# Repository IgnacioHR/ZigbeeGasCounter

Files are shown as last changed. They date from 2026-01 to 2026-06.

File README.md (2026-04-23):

# Zigbee GAS counter

This project is a DIY Zigbee-enabled gas meter that measures and tracks gas consumption. The device integrates with Zigbee2MQTT and Home Assistant, providing accurate readings for energy management and analysis. It’s designed to be battery-powered and operate autonomously, addressing common challenges of similar solutions.

## Features

- Real-time gas consumption tracking in cubic meters (m³).
- Real-time gas flow tracking in cubit meters per hour (m³/h)
- Zigbee communication for seamless integration with Zigbee2MQTT and Home Assistant.
- Battery-powered for installation flexibility.
- Double battery connector to allow battery replacement without counting interruption.
- Built-in counter to prevent data loss if the network or Home Assistant goes offline.
- Easy setup and minimal hardware requirements.
- OTA firmware updatable.
- Device button with rich functionality 

## Screenshots

Below are some screenshots of the device integrated into Zigbee2MQTT:

Main device
Exposes
Bind
Reporting
Clusters

## Why Zigbee for DIY Projects?

Zigbee is a low-power, reliable wireless protocol ideal for IoT devices. Unlike Wi-Fi, Zigbee consumes minimal energy, making it perfect for battery-operated devices. While commercial Zigbee gas meters aren’t readily available, this project demonstrates how to build one from scratch using affordable components and the ESP32-C6 module.

## How It Works

1. The gas meter’s rotating wheel has a built-in magnet.
1. A magnetic sensor detects each full rotation of the wheel, corresponding to a predefined volume of gas.
1. The ESP32-C6 processes the data, maintaining a cumulative counter (currentSummDelivered) and calculating instantaneous demand (instantaneousDemand) in m³/h.
1. These metrics are sent via Zigbee to Zigbee2MQTT, which forwards them to Home Assistant.

## Motivation

Before this project, I used a modified door sensor to monitor gas usage. While functional, it had several drawbacks:

1. **Short battery life**: The door sensor required frequent battery replacements.
2. **Data loss**: If Zigbee2MQTT or Home Assistant went offline, pulse data was lost, leading to discrepancies.
3. **Complexity**: Managing counters and automations in Home Assistant was cumbersome.

After searching for commercial Zigbee gas meters and finding none, I decided to create a custom device tailored to my needs.

Old device

## Device button functionality

The device button has implemented gesture recognition. The gestures signaled are PRESS, RELEASE, SINGLE_CLICK, DOUBLE_CLICK and HOLD. In the code there are more gestures such as NONE (No current gesture set) and UNKNOWN_CLICK (set when failing to recognize any of the properly defined gestures).

Once a gesture is recognized, the functionality attached, if any, is raised:

- PRESS: The button is pressed. The internal led is switched on. Zigbee radio is enabled.
- SINGLE_CLICK: The button is pressed and released in less than 400ms and not pressed again in 400ms. Force report of the Current Summation Delivered, Battery percentage, Status and extended Status registers. The Battery voltage is updated internally at this time. Note it is not reported because it is not possible in the Zigbee specifications.
- DOUBLE_CLICK: The button is pressed and releasses in less than 400ms, then pressed again in less than 400ms and released in less than 400ms and not pressed in less than 400ms. The device is restarted (counter is not reset)
- HOLD: The button is keep pressed for 3 seconds. The device leaves the network and starts comission process to find another network.
- NONE: The led is turned off, note the led is turned off for multiple other causes such as entering sleep mode etc.

## Project Status

April 23rd 2026 - First results of battery total duration in Light-Sleep and Deep-Sleep configurations. See below. OTA issues are now fixed
March 2nd 2026 - Now testing in LIGHT_SLEEP mode.This project is in testing phase. It is now deployed for real gas consumption measurement at home.

Remaining issues are:

* (Voltage should be transmitted now, but this is not fully tested) Voltage value is not transmitted to the server as part of the value report (in zigbee terms) I actually I know i can force read the value from the server but I don't know how to push the value from the device to the server.

* (This is now a lesson learned, not an issue) The initial decission about using a 2S LiPo battery causes more troubles than benefits. I finally decided to go 1S LiPo battery and use the internal Seed-Studio 3v switching regulator and charger module.

* (April 2026 this is now fixed) OTA is no longer functional at all. I know about changes around OTA functionality in zigbee2mqtt and more testing is required.

### What is missing and how you can help

See the **Project Status** section above for specific issues. If you can help I'll be more than happy.

For discussions and contributions, please join the ongoing thread on the Home Assistant Community: 👉 [Zigbee Gas Counter](https://community.home-assistant.io/t/zigbee-gas-counter/833557)

One of my main concerns is **power consumption and battery life**. The software includes battery status measuring and reporting.
#### First comparison analysis of the battery duration under Light-Sleep and Deep-Sleep configurations
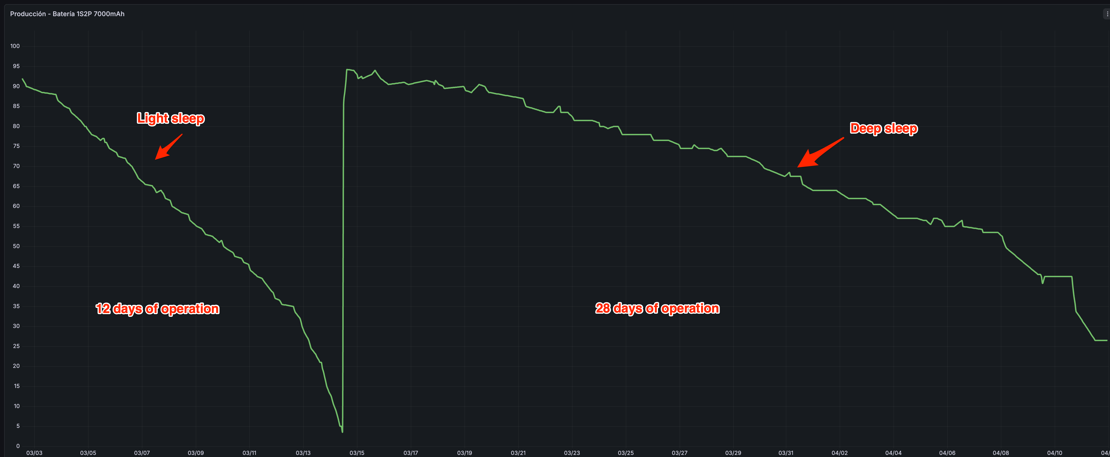
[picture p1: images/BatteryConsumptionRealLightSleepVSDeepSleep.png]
Main device


I've recently seen [this video](https://youtu.be/KE7bOYCYETM?si=DaY46TMaGhLbYbze) from @"Microamp Home" on YT and it looks worth testing using one of the devices from Nordic Semiconductors.

Currently, the testing prototype runs on a Seed Studio ESP32-C6, but the long-term goal is to use only the **ESP32-C6 chip**, eliminating unnecessary components. To achieve this, I will need help reviewing schematics and PCB designs, as **I’m not an expert in hardware design—just an enthusiast**. If you have experience in this area, your input would be greatly appreciated.

## Getting Started

### Required Hardware

To build this project, you’ll need:

- **Seed Studio ESP32-C6** or a compatible development board.
- **Magnetic reed switch** for pulse detection.
- **10kΩ resistors** (pull-down).
- **3.6 LiPo battery**. TBD
- Optional: Custom 3D-printed enclosure for the hardware.
- Optional: External 2.4 Ghz antena.

### Software Requirements

- **ESP-IDF (Espressif IoT Development Framework)**: [Installation Guide](https://docs.espressif.com/projects/esp-idf/en/latest/esp32/get-started/index.html)
- **Zigbee2MQTT**: [Setup Guide](https://www.zigbee2mqtt.io/)
- **Home Assistant**: [Official Website](https://www.home-assistant.io/)

## **Setup Instructions**

### **1. Clone the Repository**

First, download the project code from the GitHub repository:

```bash
git clone https://github.com/IgnacioHR/ZigbeeGasCounter.git
cd ZigbeeGasCounter
```

### **2. Configure the target chip**

Set the corrent target for the ESP32-C6:

```bash
idf.py --preview set-target ESP32C6
```

### **3. Install Dependencies**

Ensure ESP-IDF and its tools are installed on your machine.

### **4. Erase Flash Memory**

Clear previous configurations:

```bash
idf.py -p PORT erase-flash
```

### **4. Build and Flash**

Compile the code and flash it to the ESP32-C6 board:

```bash
idf.py build
idf.py -p PORT flash
idf.py -p PORT monitor
```

### **5. Hardware configuration in the source code

Edit the file *esp_zb_gas_meter.h* and head to the section **FEATURES CONFIGURATION** and the section **HARDWARE CONFIGURATION** you can change the chip pins to be used or leave them as they are. You can also decide what features shall be enabled depending, for example, in the power source for your specific unig.

## Device operation and main button actions

The device has just one button, but multiple gestures are recognized

- Button press: When the main button is pressed, if the device was is sleep mode, zigbee radio is enabled. Note, button press is the first gesture of a possible list of gestures recognized
- Button release: No specific action is associated to this gesture. The time passed between the button press and release is used to determine more gestures as defined below.
- Single click: A single click is detected when the time between press and release is shorter than 250ms. When single click gesture is detected, the device shall refresh data on the server side, including the battery status and voltage value (note the voltage value is not refresh in the server side automatically, there is a note on this topic), device error conditions are reset and reevaluated again.
- Double click: A double click is detected when the time between press and release is sorter then 250ms and the button cycle is executed twice. When this gesture is recognized the device is reset.
- Unknown click: This happens when the user triple-click or press-click-press in a way that does not fit in a single or double click. No action is associated to this gesture.
- Long press: When the button is pressed and not released for 3 seconds, the device is ordered to leave the network and start the commision process to join an open network again.

### NVS (Non-Volatile Storage)

The cumulative gas consumption (currentSummDelivered) is stored in the device’s NVS to prevent data loss. The counter is automatically restored upon reboot.

### Battery Optimization

The device uses sleep modes to conserve energy. It wakes up:

- When gas consumption is detected.
- Periodically (e.g., every hour) to send reports.

## Customization

You can adapt this project for other pulse-based meters (e.g., water or electricity) by modifying the code to reflect the appropriate measurement units and formulas.

## Manufacturer information

This project includes a custom manufacturer name and code:

- Name: “MICASA” – A playful mix of “mi casa” (my home) in Spanish.
- Code: 0x8888 – Chosen arbitrarily for this DIY project.

## SDK Resources

- [ESP Zigbee SDK Docs](https://docs.espressif.com/projects/esp-zigbee-sdk)
- [ESP Zigbee SDK Repo](https://github.com/espressif/esp-zigbee-sdk)

## Contributing

If you want to contribute or improve this project, feel free to fork the repository and open a pull request. Suggestions are welcome!

## TODO

Here are the planned improvements:

1. Design a custom PCB for the ESP32-C6, connectors and resistors.
2. Create a 3D-printed enclosure for secure installation.
3. Light-Sleep mode, the chip is not entering Light-Sleep

## Acknowledgments

By improving the content structure and emphasizing actionable steps, this README not only serves as a guide for your project but also inspires others to create their own Zigbee devices.

## License

[License](https://creativecommons.org/licenses/by-nc-sa/4.0/deed.en)

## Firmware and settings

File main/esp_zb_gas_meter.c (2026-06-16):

/*
 * Zigbee Gas Meter - An open-source Zigbee gas meter project.
 * Copyright (c) 2025 Ignacio Hernández-Ros.
 *
 * This work is licensed under the Creative Commons Attribution-NonCommercial-ShareAlike 4.0
 * International License. To view a copy of this license, visit
 * https://creativecommons.org/licenses/by-nc-sa/4.0/
 *
 * You may use, modify, and share this work for personal and non-commercial purposes, as long
 * as you credit the original author(s) and share any derivatives under the same license.
 */
#include <string.h>
#include "esp_check.h"
#include "driver/gpio.h"
#include "nvs_flash.h"
#include "freertos/FreeRTOS.h"
#include "freertos/task.h"
#include "esp_sleep.h"
#include "sys/time.h"
#include "esp_timer.h"

#include "esp_zb_gas_meter.h"
#include "esp_zb_gas_meter_adc.h"
#include "esp_zb_gas_meter_zigbee.h"
#include "esp_zb_gas_ota.h"
#include "esp_zb_gas_led.h"

/* Experimental, check if we sleepy device can help the design */
#ifdef CONFIG_PM_ENABLE
#include "esp_pm.h"
#include "esp_private/esp_clk.h"
#endif

// amount of time to ignore a digital input pin interrupt repetition
#define REED_DEBOUNCE_TIMEOUT 1000U /* milliseconds */
#define BTN_DEBOUNCE_TIMEOUT 30 /* milliseconds */

/* Human interaction and device configuration */

// How long the MAIN BUTTON must be pressed to consider a LONG PRESS
#define LONG_PRESS_TIMEOUT 5 // seconds

#define NVS_NAMESPACE "gas_monitor"
#define NVS_KEY "counter"

#ifdef FEATURE_MEASURE_FLOW_RATE
#define TIME_TO_RESET_INSTANTANEOUS_D UINT32_C(12000)
#endif

const char *TAG = "GAS_COUNTER";

// Last time a pulse was received

// last time an interrupt occurred
RTC_DATA_ATTR struct timeval last_interrupt_time;

// RTC_DATA_ATTR int last_reel_state;
RTC_DATA_ATTR struct timeval last_reel_state_chage_time;

#ifdef FEATURE_MEASURE_FLOW_RATE
RTC_DATA_ATTR struct timeval last_increment_time;
#endif

// gracie period to avoid entering deep sleep when the zigbee radio has been turned on
#ifdef FEATURE_DEEP_SLEEP
struct timeval deep_sleep_gracie_period = {
    .tv_sec = 0,
    .tv_usec = 0
};
#endif

// When the main button is pressed a one time task is started
// to detect a long press without having to wait until
// the user releases the button
#ifdef FEATURE_DEEP_SLEEP
bool started_from_deep_sleep = false;
#endif

// true while leaving the network to prevent sending data to coordinator
bool leaving_network = false;

#ifdef FEATURE_DEEP_SLEEP
// sleep
RTC_DATA_ATTR struct timeval sleep_enter_time;
#endif

// Non volatile memory handle
nvs_handle_t my_nvs_handle;

#ifdef FEATURE_MEASURE_BATTERY_LEVEL
TaskHandle_t adc_task_handle = NULL;
#endif
TaskHandle_t zigbee_task_handle = NULL;
#ifdef FEATURE_DEEP_SLEEP
TaskHandle_t deep_sleep_task_handle = NULL;
#endif
TaskHandle_t save_counter_task_handle = NULL;
TaskHandle_t btn_press_task_handle = NULL;
TaskHandle_t btn_release_task_handle = NULL;
#ifdef FEATURE_DEEP_SLEEP
QueueHandle_t deep_sleep_queue_handle = NULL;
#endif
#ifdef FEATURE_MEASURE_FLOW_RATE
TimerHandle_t reset_instantaneous_demand_timer = NULL;
#endif
TimerHandle_t deep_sleep_timer = NULL;
#ifdef FEATURE_LIGHT_SLEEP
TimerHandle_t periodic_checks_timer = NULL;  // Timer for periodic radio/battery checks (event-driven instead of polling)
#endif
EventGroupHandle_t report_event_group_handle = NULL;
EventGroupHandle_t main_event_group_handle = NULL;

// Intelligent button gesture detection timers
TimerHandle_t timer_since_press_handler = NULL;
TimerHandle_t t_detect_hold = NULL;
TimerHandle_t timer_since_release_handler = NULL;

TaskHandle_t btn_task_handle = NULL;

// this is set to true when the device goes to sleep and the pulse pin is
// still high. The device will be turned on inmediately and we will
// avoid counting one tick until we detect it is down again
RTC_DATA_ATTR bool exception_pulse_button_on_hold = false;

#define CLICK_PRESS_TIME_MS       400    // MUST BE BIGGER THAN 150
#define CLICK_HOLD_TIME_MS       3000
#define CLICK_RELEASE_TIME_MS     400

typedef enum ButtonState_e {
    NONE = 0,
    PRESS,
    RELEASE,
    SINGLE_CLICK,
    DOUBLE_CLICK,
    UNKNOWN_CLICK,
    HOLD
} button_state_t;

button_state_t button_state = NONE;

// static portMUX_TYPE counter_spinlock = portMUX_INITIALIZER_UNLOCKED;

// Load counter value from NVS
esp_err_t gm_counter_load_nvs()
{
    esp_err_t err = nvs_open(NVS_NAMESPACE, NVS_READWRITE, &my_nvs_handle);
    if (err == ESP_OK)
    {
        uint64_t saved_count = 0;
        err = nvs_get_u64(my_nvs_handle, NVS_KEY, &saved_count);
        if (err == ESP_OK)
        {
            current_summation_delivered.low = saved_count & 0x00000000FFFFFFFF;
            current_summation_delivered.high = (saved_count & 0x0000FFFF00000000) >> 32;
            ESP_LOGI(TAG, "Counter loaded: low=%lu high=%u", current_summation_delivered.low, current_summation_delivered.high);
        }
        else
        {
            ESP_LOGI(TAG, "Counter not found in memory so starting from 0");
            err = ESP_OK;
        }
    }
    else
    {
        device_extended_status |= ESP_ZB_ZCL_METERING_NV_MEMORY_ERROR;
        device_status |= ESP_ZB_ZCL_METERING_GAS_CHECK_METER;
        xEventGroupSetBits(report_event_group_handle, STATUS_REPORT | EXTENDED_STATUS_REPORT);

        ESP_LOGE(TAG, "Error opening NVS: %s", esp_err_to_name(err));
    }
    return err;
}

// Task to save the counter to NVS when value changes
void save_counter_task(void *arg)
{
    while (true)
    {
        ulTaskNotifyTake(pdTRUE, portMAX_DELAY);
        uint64_t to_save_count = current_summation_delivered.high;
        to_save_count <<= 32;
        to_save_count |= current_summation_delivered.low;
        esp_err_t err = nvs_set_u64(my_nvs_handle, NVS_KEY, to_save_count);
        if (err == ESP_OK)
        {
            nvs_commit(my_nvs_handle);
            ESP_LOGI(TAG, "Counter stored: low=%lu high=%d", current_summation_delivered.low, current_summation_delivered.high);
            #ifdef FEATURE_DEEP_SLEEP
            if (deep_sleep_task_handle != NULL)
            {
                TickType_t deep_sleep_time = dm_deep_sleep_time_ticks();
                if (xQueueSendToFront(deep_sleep_queue_handle, &deep_sleep_time, pdMS_TO_TICKS(100)) != pdTRUE)
                    ESP_LOGE(TAG, "Can't reschedule deep sleep timer");
            }
            #endif
        }
        else
        {
            device_extended_status |= ESP_ZB_ZCL_METERING_NV_MEMORY_ERROR;
            device_status |= ESP_ZB_ZCL_METERING_GAS_CHECK_METER;
            xEventGroupSetBits(report_event_group_handle, STATUS_REPORT | EXTENDED_STATUS_REPORT);
            ESP_LOGE(TAG, "Error saving NVS: %s", esp_err_to_name(err));
        }
        led_off();
    }
}

// Set counter value and save
esp_err_t gm_counter_set(const esp_zb_uint48_t *new_value)
{
    current_summation_delivered.low = new_value->low;
    current_summation_delivered.high = new_value->high;
    uint64_t current_summation_64 = current_summation_delivered.high;
    current_summation_64 <<= 32;
    current_summation_64 |= current_summation_delivered.low;
    xEventGroupSetBits(report_event_group_handle, CURRENT_SUMMATION_DELIVERED_REPORT);
    xTaskNotifyGive(save_counter_task_handle);
    return ESP_OK;
}

// Reset counter value to 0 and save
esp_err_t gm_counter_reset()
{
    esp_zb_uint48_t zero = {
        .low = 0,
        .high = 0};
    return gm_counter_set(&zero);
}

// Helper function to return the time in milliseconds since now and the other timeval
// received as a parameter
int32_t time_diff_ms(const struct timeval *other)
{
    struct timeval now;
    gettimeofday(&now, NULL);
    int32_t time_diff = (now.tv_sec - other->tv_sec) * 1000L + (now.tv_usec - other->tv_usec) / 1000L;
    return time_diff;
}

bool check_reel_state_change_is_ok(int level) {
    bool is_ok = last_reel_state_chage_time.tv_sec == 0 && last_reel_state_chage_time.tv_usec == 0;
    if (!is_ok) {
        int32_t elapsed_time_since_last_state_change = time_diff_ms(&last_reel_state_chage_time);
        // ESP_LOGI(TAG, "Elapsed time since last state change %ld", elapsed_time_since_last_state_change);
        is_ok = /*level != last_reel_state &&*/ elapsed_time_since_last_state_change > 150;
    }
    if (is_ok) {
        // transition detected
        // last_reel_state = level;
        gettimeofday(&last_reel_state_chage_time, NULL);
    }
    return is_ok;
}

// Check conditions to enable radio.
// There are 2 possible conditions:
// - time pass since last report
// - counter increased 10 times
void check_shall_enable_radio()
{
    if (zigbee_task_handle == NULL)
    {
        bool enable_radio =
            (last_report_sent_time.tv_sec == 0 && last_report_sent_time.tv_usec == 0) ||
            (time_diff_ms(&last_report_sent_time) / 1000 >= MUST_SYNC_MINIMUM_TIME);
        if (!enable_radio && last_summation_sent > 0)
        {
            uint64_t current_summation_64 = current_summation_delivered.high;
            current_summation_64 <<= 32;
            current_summation_64 |= current_summation_delivered.low;
            enable_radio = current_summation_64 - last_summation_sent >= COUNTER_REPORT_DIFF;
        }
        if (enable_radio)
        {
            xEventGroupSetBits(main_event_group_handle, SHALL_ENABLE_ZIGBEE);
            xEventGroupSetBits(report_event_group_handle, CURRENT_SUMMATION_DELIVERED_REPORT);
        }
    }
}

#ifdef FEATURE_MEASURE_BATTERY_LEVEL
// Computes if it is needed to measure battery voltage
void check_shall_measure_battery()
{
    bool measure_battery =
        (last_battery_measurement_time.tv_sec == 0 && last_battery_measurement_time.tv_usec == 0) ||
        (time_diff_ms(&last_battery_measurement_time) / 1000 >= MEASURE_BATTERY_VOLTAGE_TIME);
    if (measure_battery)
    {
        // battery voltage is measured with zigbee radio
        // turned on
        xEventGroupSetBits(main_event_group_handle, SHALL_MEASURE_BATTERY);
        xEventGroupSetBits(report_event_group_handle, CURRENT_SUMMATION_DELIVERED_REPORT);
    }
}
#endif

#ifdef FEATURE_LIGHT_SLEEP
// Periodic callback to check if radio or battery measurement is needed
// Called every MUST_SYNC_MINIMUM_TIME seconds instead of polling every 250ms
void periodic_checks_callback(TimerHandle_t xTimer)
{
    #ifdef FEATURE_MEASURE_BATTERY_LEVEL
    check_shall_measure_battery();
    #endif
    check_shall_enable_radio();
}
#endif

#ifdef FEATURE_MEASURE_FLOW_RATE
// After two consecutive values of current_summation_delivered this method
// computes the instantaneous_demand
// NOTE: there is one special task to set instantaneous demand to 0 when no
// values arrive
void gm_compute_instantaneous_demand(int time_diff_ms, bool fromISR)
{
    float time_diff_h = time_diff_ms / (1000.0 * 3600.0); // Convert time to hours/100
    int32_t _instantaneous_demand;
    if (time_diff_h > 0)
    {
        _instantaneous_demand = (int32_t)((1 / time_diff_h) + 0.5); // compute flow in m³/h
    }
    else
    {
        _instantaneous_demand = 0;
    }
    // check for a real change in the value
    esp_zb_int24_t new_instantaneous_demand;
    new_instantaneous_demand.low = _instantaneous_demand & 0x0000FFFF;
    new_instantaneous_demand.high = (_instantaneous_demand & 0x00FF0000) >> 16;
    if (new_instantaneous_demand.low != instantaneous_demand.low || new_instantaneous_demand.high != instantaneous_demand.high)
    {
        instantaneous_demand.low = new_instantaneous_demand.low;
        instantaneous_demand.high = new_instantaneous_demand.high;
        if (fromISR)
        {
            BaseType_t mustYield = pdFALSE;
            xEventGroupSetBitsFromISR(report_event_group_handle, INSTANTANEOUS_DEMAND_REPORT, &mustYield);
            portYIELD_FROM_ISR(mustYield);
            mustYield = pdFALSE;
            if (xTimerStartFromISR(reset_instantaneous_demand_timer, &mustYield) != pdPASS)
            {
                ESP_LOGE(TAG, "Can't reset instantaneous demand timer");
            }
            portYIELD_FROM_ISR(mustYield);
        }
        else
        {
            xEventGroupSetBits(report_event_group_handle, INSTANTANEOUS_DEMAND_REPORT);
            if (xTimerStart(reset_instantaneous_demand_timer, pdMS_TO_TICKS(100)) != pdPASS)
            {
                ESP_LOGE(TAG, "Can't reset instantaneous demand timer");
            }
        }
    }
}
#endif

// Adds one to current_summation_delivered and nothing else
void gm_counter_increment(bool fromISR)
{
    led_on();
    current_summation_delivered.low += 1; // Adds up 1 cent of m³
    if (current_summation_delivered.low == 0)
    {
        current_summation_delivered.high += 1;
    }
    uint64_t current_summation_64 = current_summation_delivered.high;
    current_summation_64 <<= 32;
    current_summation_64 |= current_summation_delivered.low;
    if (fromISR)
    {
        BaseType_t mustYield = pdFALSE;
        xEventGroupSetBitsFromISR(report_event_group_handle, CURRENT_SUMMATION_DELIVERED_REPORT, &mustYield);
        portYIELD_FROM_ISR(mustYield);
        mustYield = pdFALSE;
        vTaskNotifyGiveFromISR(save_counter_task_handle, &mustYield);
        portYIELD_FROM_ISR(mustYield);
    }
    else
    {
        xEventGroupSetBits(report_event_group_handle, CURRENT_SUMMATION_DELIVERED_REPORT);
        xTaskNotifyGive(save_counter_task_handle);
    }
    #ifdef FEATURE_MEASURE_FLOW_RATE
        if (last_increment_time.tv_sec != 0 && last_increment_time.tv_usec != 0)
            gm_compute_instantaneous_demand(time_diff_ms(&last_increment_time), fromISR);
        gettimeofday(&last_increment_time, NULL);
    #endif
}

// function called when the device leaves the zigee network
void leave_callback(esp_zb_zdp_status_t zdo_status, void *args)
{
    leaving_network = false;
    ESP_LOGI(TAG, "Leave status 0x%x", zdo_status);
}

void leave_action()
{
    if (esp_zb_bdb_dev_joined())
    {
        ESP_LOGI(TAG, "Leaving network");
        #ifdef FEATURE_DEEP_SLEEP
        xEventGroupSetBits(main_event_group_handle, SHALL_STOP_DEEP_SLEEP);
        #endif
        leaving_network = true;
        esp_zb_zdo_mgmt_leave_req_param_t leave_request = {
            .device_address = {},
            .dst_nwk_addr = 0xFFFF,
            .remove_children = 0,
            .rejoin = 0};
        esp_zb_get_long_address(leave_request.device_address);
        esp_zb_zdo_device_leave_req(&leave_request, leave_callback, NULL);
    } else {
        ESP_LOGE(TAG, "Short address is 0xFFFE so not leaving network!");
    }
}

#ifdef FEATURE_DEEP_SLEEP
// Compute how long to wait for sleep depending on device conditions
TickType_t dm_deep_sleep_time_ticks()
{
    const TickType_t before_deep_sleep_time_ticks = (zigbee_task_handle != NULL ? TIME_TO_SLEEP_ZIGBEE_ON : TIME_TO_SLEEP_ZIGBEE_OFF);
    ESP_LOGD(TAG, "Start one-shot timer for %ldms to enter the deep sleep", before_deep_sleep_time_ticks);
    return before_deep_sleep_time_ticks;
}

// task to govern the deep sleep timeout
void deep_sleep_controller_task(void *arg)
{
    ESP_LOGI(TAG, "Deep sleep task started");
    led_off();
    while (true)
    {
        TickType_t new_timer_value;
        if (xQueueReceive(deep_sleep_queue_handle, &new_timer_value, portMAX_DELAY) == pdTRUE)
        {
            // REMOVE FOR PRODUCTION. We are going to disable deep sleep for testing
            // if (xTimerStop(deep_sleep_timer, pdMS_TO_TICKS(100)) != pdPASS)
            // {
            //     ESP_LOGE(TAG, "Can't stop deep sleep timer");
            // }
            ESP_LOGI(TAG, "Deep sleep timer value received %d", new_timer_value);
            if (deep_sleep_gracie_period.tv_sec > 0) {
                int elapsed = time_diff_ms(&deep_sleep_gracie_period);
                if (elapsed < 0) {
                    ESP_LOGI(TAG, "Deep sleep timer Under grace period, ignored");
                    continue;
                }
            }
            if (new_timer_value == portMAX_DELAY)
            {
                if (xTimerStop(deep_sleep_timer, pdMS_TO_TICKS(100)) != pdPASS)
                {
                    ESP_LOGE(TAG, "Can't stop deep sleep timer");
                }
            }
            else
            {
                if (xTimerIsTimerActive(deep_sleep_timer) == pdFALSE) {
                    ESP_LOGI(TAG, "Deep sleep timer started");
                    xTimerStart(deep_sleep_timer, new_timer_value);
                } else {
                    if (xTimerChangePeriod(deep_sleep_timer, new_timer_value, pdMS_TO_TICKS(100)) != pdPASS)
                    {
                        ESP_LOGE(TAG, "Can't change deep sleep timer time");
                    }
                }
            }
        }
    }
}
#endif
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
void app_main(void)
{
    esp_log_level_set("*", ESP_LOG_ERROR);
    esp_log_level_set(TAG, ESP_LOG_INFO);
    ESP_LOGD(TAG, "\n");
    ESP_LOGI(TAG, "Starting Zigbee GasCounter...");
    esp_err_t reset_error = report_reset_reason();

    #ifdef FEATURE_DEEP_SLEEP
    ESP_ERROR_CHECK((deep_sleep_timer = xTimerCreate("deep_sleep_timer", portMAX_DELAY, pdFALSE, "d_s_t", enter_deep_sleep_cb)) == NULL ? ESP_FAIL : ESP_OK);
    #endif

    // intelligent button timers
    ESP_ERROR_CHECK((timer_since_press_handler = xTimerCreate("0.2s_since_press", pdMS_TO_TICKS(CLICK_PRESS_TIME_MS), pdFALSE, "2_t_p", timer_since_press_cb)) == NULL ? ESP_FAIL : ESP_OK);
    ESP_ERROR_CHECK((t_detect_hold = xTimerCreate("4s_since_press", pdMS_TO_TICKS(CLICK_HOLD_TIME_MS), pdFALSE, "4_s_p", timer_detect_hold_cb)) == NULL ? ESP_FAIL : ESP_OK);
    ESP_ERROR_CHECK((timer_since_release_handler = xTimerCreate("0.2s_since_release", pdMS_TO_TICKS(CLICK_RELEASE_TIME_MS), pdFALSE, "2_t_r", timer_since_release_cb)) == NULL ? ESP_FAIL : ESP_OK);

    // Periodic timer for radio/battery checks (replaces 250ms polling)
    // Set period to slightly less than MUST_SYNC_MINIMUM_TIME to ensure checks happen
    #ifdef FEATURE_LIGHT_SLEEP
    ESP_ERROR_CHECK((periodic_checks_timer = xTimerCreate("periodic_checks", pdMS_TO_TICKS(MUST_SYNC_MINIMUM_TIME * 1000 - 100), pdTRUE, "p_c", periodic_checks_callback)) == NULL ? ESP_FAIL : ESP_OK);
    if (periodic_checks_timer != NULL) {
        xTimerStart(periodic_checks_timer, 0);
    }
    #endif

    #ifdef FEATURE_DEEP_SLEEP
    ESP_ERROR_CHECK((deep_sleep_queue_handle = xQueueCreate(1, sizeof(TickType_t))) == NULL ? ESP_FAIL : ESP_OK);
    #endif
    ESP_ERROR_CHECK((main_event_group_handle = xEventGroupCreate()) == NULL ? ESP_FAIL : ESP_OK);
    ESP_ERROR_CHECK((report_event_group_handle = xEventGroupCreate()) == NULL ? ESP_FAIL : ESP_OK);
    ESP_ERROR_CHECK(xTaskCreate(save_counter_task, "save_counter", 2048, NULL, 15, &save_counter_task_handle) != pdPASS);
    ESP_ERROR_CHECK(xTaskCreate(btn_press_task, "btn_press", 2048, NULL, 5, &btn_press_task_handle) != pdPASS);
    ESP_ERROR_CHECK(xTaskCreate(btn_release_task, "btn_release", 2048, NULL, 5, &btn_release_task_handle) != pdPASS);
    ESP_ERROR_CHECK(xTaskCreate(btn_task, "btn_task", 2048, NULL, 5, &btn_task_handle) != pdPASS);
    #ifdef FEATURE_MEASURE_BATTERY_LEVEL
    ESP_ERROR_CHECK(xTaskCreate(adc_task, "adc", 4096, NULL, 10, &adc_task_handle) != pdPASS);
    #endif
    #ifdef FEATURE_MEASURE_FLOW_RATE
    ESP_ERROR_CHECK((reset_instantaneous_demand_timer = xTimerCreate("reset_inst_dema", pdMS_TO_TICKS(TIME_TO_RESET_INSTANTANEOUS_D), pdFALSE, "r_i_d", reset_instantaneous_demand_cb)) == NULL ? ESP_FAIL : ESP_OK);
    #endif

    if (reset_error != ESP_OK) {
        xEventGroupSetBits(report_event_group_handle, EXTENDED_STATUS_REPORT);
    }

    ESP_LOGI(TAG, "Configuring led");
    ESP_ERROR_CHECK(config_led());
    ESP_LOGI(TAG, "Led ON");
    ESP_LOGI(TAG, "Configuring GPIO Interrupt...");
    ESP_ERROR_CHECK(gm_gpio_interrup_init());
    ESP_LOGI(TAG, "Configuring NVS Flash");
    ESP_ERROR_CHECK(nvs_flash_init());
    ESP_LOGI(TAG, "Configuring power save");
    ESP_ERROR_CHECK(esp_zb_power_save_init());
    ESP_LOGI(TAG, "Load counter from NVS");
    ESP_ERROR_CHECK(gm_counter_load_nvs());
    ESP_LOGI(TAG, "Setup deep sleep");
    ESP_ERROR_CHECK(gm_deep_sleep_init());
    // led_on();
    xEventGroupSetBits(report_event_group_handle, CURRENT_SUMMATION_DELIVERED_REPORT);

    // start main loop
    ESP_LOGI(TAG, "Starting main loop");
    ESP_ERROR_CHECK(xTaskCreate(gm_main_loop_task, "gas_meter_main", 8192, NULL, tskIDLE_PRIORITY, NULL) != pdPASS);
}

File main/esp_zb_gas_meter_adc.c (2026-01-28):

/*
 * Zigbee Gas Meter - An open-source Zigbee gas meter project.
 * Copyright (c) 2025 Ignacio Hernández-Ros.
 *
 * This work is licensed under the Creative Commons Attribution-NonCommercial-ShareAlike 4.0
 * International License. To view a copy of this license, visit
 * https://creativecommons.org/licenses/by-nc-sa/4.0/
 *
 * You may use, modify, and share this work for personal and non-commercial purposes, as long
 * as you credit the original author(s) and share any derivatives under the same license.
 */
#include <string.h>
#include "esp_check.h"
#include "driver/gpio.h"
#include "freertos/FreeRTOS.h"
#include "zcl/esp_zigbee_zcl_metering.h"

#include "esp_zb_gas_meter.h"

#ifdef MEASURE_BATTERY_LEVEL

#include "esp_zb_gas_meter_zigbee.h"
#include "esp_zb_gas_meter_adc.h"
#include "esp_zb_gas_meter_adc_zigbee.h"

#include "esp_adc/adc_continuous.h"
#include "esp_adc/adc_cali.h"
#include "esp_adc/adc_cali_scheme.h"

// output - pin to enable battery voltage to the adc converter
#define BAT_MON_ENABLE                      GPIO_NUM_21

uint8_t battery_voltage = 0;
uint8_t battery_percentage = 0;
uint32_t battery_alarm_state = 0;

#define M                       ((double)MAX_BATTERY_VOLTAGE / (double)ADC_MAX_VALUE)
#define ADC_MIN_VALUE           (((double)MIN_BATTERY_VOLTAGE)/M)
#define TO_PERCENTAGE           (double)(200.0 / ((double)ADC_MAX_VALUE - (double)ADC_MIN_VALUE))

// required by the Zigbee power cluster attributes
uint8_t battery_voltage_min = UINT8_C(MIN_BATTERY_VOLTAGE/100);
uint8_t battery_voltage_th1 = UINT8_C(WARN_BATTERY_VOLTAGE/100);

struct timeval last_battery_measurement_time;

adc_channel_t channel = ADC_CHANNEL_2; // ADC_CHANNEL_3 is a better option, but the current board was using 0 so let's change it now GPIO 3
adc_continuous_handle_t handle = NULL;

void set_battery_unavailable()
{
    battery_alarm_state |= ESP_ZB_ZCL_POWER_CONFIG_MAINS_ALARM_MASK_VOLTAGE_UNAVAIL; // Battery unavailable bit set
    ESP_LOGE(TAG, "Battery marked unavailable");
    xEventGroupSetBits(report_event_group_handle, BATTERY_REPORT);
}

// Hardware configuration of ADC related pins
void bat_adc_hardware_config()
{
    uint64_t bat_volt_enable_pin = 1ULL << BAT_MON_ENABLE;
    gpio_config_t voltage_enable_conf = {
        .intr_type = GPIO_INTR_DISABLE,
        .mode = GPIO_MODE_OUTPUT,
        .pin_bit_mask = bat_volt_enable_pin,
        .pull_down_en = GPIO_PULLDOWN_DISABLE,
        .pull_up_en = GPIO_PULLUP_DISABLE};
    if (gpio_config(&voltage_enable_conf) != ESP_OK) {
        ESP_LOGE(TAG, "Can't config gpio for BAT_MON_ENABLE pin");
        set_battery_unavailable();
    }
}

esp_err_t bat_adc_calibration_init(const adc_unit_t unit, const adc_channel_t channel, const adc_atten_t atten, adc_cali_handle_t *out_handle)
{
    adc_cali_handle_t handle = NULL;
    esp_err_t error = ESP_FAIL;

    ESP_LOGD(TAG, "calibration scheme version is Curve Fitting");
    adc_cali_curve_fitting_config_t cali_config = {
        .unit_id = unit,
        .chan = channel,
        .atten = atten,
        .bitwidth = ADC_BITWIDTH_DEFAULT,
    };
    error = adc_cali_create_scheme_curve_fitting(&cali_config, &handle);

    *out_handle = handle;
    if (error == ESP_OK) {
        ESP_LOGD(TAG, "Calibration Success");
    } else if (error == ESP_ERR_NOT_SUPPORTED) {
        ESP_LOGW(TAG, "eFuse not burnt, skip software calibration");
    } else {
        ESP_LOGE(TAG, "Invalid arg or no memory");
    }

    return error;
}

esp_err_t bat_adc_calibration_deinit(const adc_cali_handle_t handle)
{
    ESP_LOGD(TAG, "deregister %s calibration scheme", "Curve Fitting");
    ESP_RETURN_ON_ERROR(adc_cali_delete_scheme_curve_fitting(handle), TAG, "Failed to delete ADC calibration curve");
    return ESP_OK;
}

bool IRAM_ATTR bat_conv_done_cb(adc_continuous_handle_t handle, const adc_continuous_evt_data_t *edata, void *user_data)
{
    BaseType_t mustYield = pdFALSE;
    //Notify that ADC continuous driver has done enough number of conversions
    vTaskGenericNotifyGiveFromISR(adc_task_handle, 1, &mustYield);

    return (mustYield == pdTRUE);
}

esp_err_t bat_continuous_adc_init(const adc_channel_t channel, adc_continuous_handle_t *out_handle)
{
    adc_continuous_handle_t handle = NULL;

    adc_continuous_handle_cfg_t adc_config = {
        .max_store_buf_size = 1024,
        .conv_frame_size = BAT_BUFFER_READ_LEN,
    };
    ESP_RETURN_ON_ERROR(adc_continuous_new_handle(&adc_config, &handle), TAG, "ADC call to adc_continuous_new_handle failed");

    adc_continuous_config_t dig_cfg = {
        .pattern_num = 1,
        .sample_freq_hz = SOC_ADC_SAMPLE_FREQ_THRES_LOW,
        .conv_mode = ADC_CONV_SINGLE_UNIT_1,
        .format = ADC_DIGI_OUTPUT_FORMAT_TYPE2,
    };

    adc_digi_pattern_config_t adc_pattern[SOC_ADC_PATT_LEN_MAX] = {0};
    adc_pattern[0].atten = ADC_ATTEN_DB_12;
    adc_pattern[0].channel = channel & 0x7;
    adc_pattern[0].unit = ADC_UNIT_1;
    adc_pattern[0].bit_width = ADC_BITWIDTH_12;
    dig_cfg.adc_pattern = adc_pattern;
    ESP_RETURN_ON_ERROR(adc_continuous_config(handle, &dig_cfg), TAG, "ADC call to continous_config failed");

    *out_handle = handle;

    return ESP_OK;
}
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

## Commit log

2026-01-10 Code cleanup and bug fixing
    [esp_zb_gas_meter.c, esp_zb_gas_meter.h, esp_zb_gas_meter_adc.c]
2026-01-11 Save today's work! bug fixing and progress on LIGHT_SLEEP
    [esp_zb_gas_meter.c, esp_zb_gas_meter.h]
2026-01-19 added timer when in light-sleep to allow comissioning to success
2026-03-13 Timins adjusted and filter of noise from reel sensor improved
    [esp_zb_gas_meter.c, esp_zb_gas_meter.h]
2026-04-04 Report battery voltage
2026-04-12 Report voltage, long detection gesture bug fix
    [esp_zb_gas_meter.c]
2026-04-23 Updated README including battery consumption analysis result
2026-05-24 bug fix. last_reel_state is not needed
    [esp_zb_gas_meter.c]
2026-06-16 fix missing variable declaration
    [esp_zb_gas_meter.c]
